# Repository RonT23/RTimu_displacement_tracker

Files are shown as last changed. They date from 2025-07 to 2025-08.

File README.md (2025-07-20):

# Real-Time Displacement Tracker

## Overview 

This project involves the design of a device used to track the displacement of a  moving building under seismic activity. It was developed as part of the final project for the Multivariable Control Systems course in the MSc program in Control Systems and Robotics. The primary goal of the device is to monitor and provide real-time state feedback for controllers applied to seismically controlled buildings.

## The Idea

Consider a building equipped with static control mechanisms, such as elastic dampers installed at its base. These dampers mitigate high-frequency vibrations caused by seismic activity and help protect the building. However, not all seismic waves are fully absorbed—residual vibrations can still propagate and cause structural damage.

The concept proposed in the paper *Robust control of base-isolated structures: Theory and experiments* (-*Kelly, Leitmann and Soldatos*), suggests that that a robust controller applied at the base of an elastomeric-isolated structure can effectively suppress superstructure motion. Their analysis provides critical design constraints for the sensor unit, including the need for high-fidelity base displacement and velocity measurements, low latency, and sufficient dynamic range to capture large isolator displacements and velocities. This project focuses on designing the sensing component that would support such a control system by providing accurate, real-time motion data.

## Hardware

* MPU6050 IMU – Inertial Measurement Unit for retrieving acceleration and gyroscope data.
* FireBeetle ESP32-C6 Mini – Microcontroller used for data acquisition, processing, and communication.
* 3D-Printed Casing – Protective enclosure for the sensor and electronic components.
* USB Cable – Used for both power supply and serial communication with a host computer.

The MPU6050 IMU communicates with the ESP32-C6 Mini microcontroller via the I2C protocol. Use the following wiring configuration to connect the sensor to the microcontroller.

<div align="center">

<table>
  <thead>
    <tr>
      <th><strong>MPU6050 Pin</strong></th>
      <th><strong>ESP32-C6 Mini Pin</strong></th>
    </tr>
  </thead>
  <tbody>
    <tr>
      <td align="center">SCL</td>
      <td align="center">IO19</td>
    </tr>
    <tr>
      <td align="center">SDA</td>
      <td align="center">IO20</td>
    </tr>
    <tr>
      <td align="center">VCC</td>
      <td align="center">3V3</td>
    </tr>
    <tr>
      <td align="center">GND</td>
      <td align="center">GND</td>
    </tr>
  </tbody>
</table>

</div>

The ESP32-C6 Mini connects to a host computer over USB for data transfer and power. To secure the electronic components, use the provided 3D model casing (`case.stl`). **Caution**: Ensure that the sensor is oriented correctly within the case—align the axis arrows on the top of the casing with the direction arrows on the sensor's PCB.

## Software 

- ESP-IDF – Software development and hardware configuration framework for ESP32-based SoC's.
- Embedded source code – Firmware for data acquisition and processing as provided in this repository.
- Python scripts – For data visualization and post-processing.

To install the ESP-IDF software please follow the guide provided by the official [webpage](https://docs.espressif.com/projects/esp-idf/en/stable/esp32/get-started/index.html). Once the ESP-IDF tools are installed successfully, make a new project by adding this repository.  

## Programming the Device 

To program the ESP32-C6 device with the provided source code, use the ESP-IDF tools:

```shell
cp -r RTimu_displacement_tracker/esp32_rtdt_app ~/esp
cd ~/esp
. ./esp-idf/export.sh
idf.py set-target esp32c6
idf.py build
idf.py -p /dev/ttyACM0 flash
```

## Build the UI

To build the executable application from the provided Python script, run the following commands on a Linux terminal:

```shell
cd disp_monitor_ui
chmod +x build.sh
./build.sh
```

For windows users use the `build.bat` script simillarly.

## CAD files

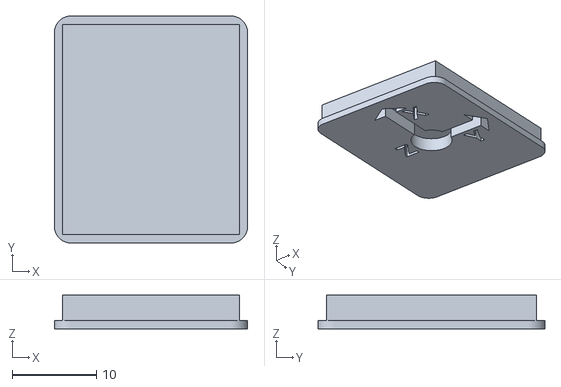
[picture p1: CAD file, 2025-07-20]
stl/top-v2.stl
23.0 x 27.0 x 4.00

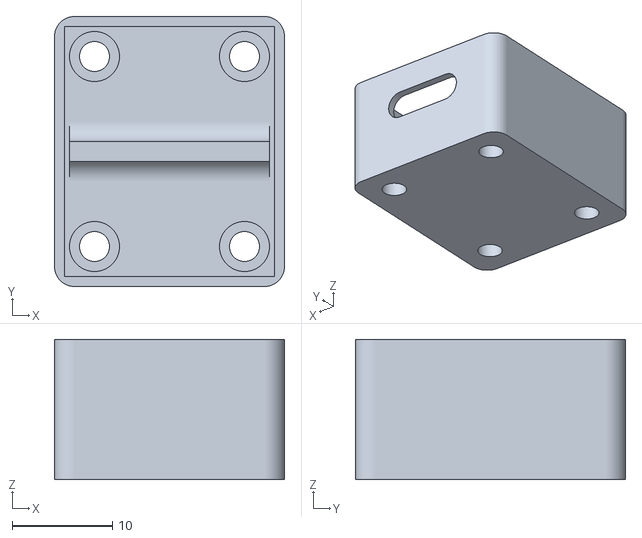
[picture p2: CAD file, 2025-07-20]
stl/base-v2.stl
23.0 x 27.0 x 14.0

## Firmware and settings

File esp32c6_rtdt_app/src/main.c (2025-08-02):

/*
 * Project: Real-Time Displacement Monitoring Unit
 * File: main.c
 * Author: Ronaldo Tsela
 * Date: July 2025
 * 
 * This is the main application entry point for the real-time displacement monitoring unit.
 * It was developed as part of the final project in the "Multivariable Control Systems" course,
 * within the MSc in Control Systems and Robotics program at the National Technical University of Athens (NTUA).
 * 
 * - This application is designed to run on the ESP32 C6.
 * - Developed using the ESP-IDF v5.4.2 framework.
 * - Uses FreeRTOS for application life cycle and execution management.
 * - Requires the MPU6050 IMU. 
 * - It includes initialization routines, data acquisition logic,
 *   and real-time processing for displacement retrival.
 * - The output is printed in CSV format through the main USB to Serial interface
 * - Read the provided documentation for more details.
 */

#include <stdio.h>
#include "freertos/FreeRTOS.h"
#include "freertos/task.h"
#include "esp_log.h"
#include "app_tasks.h"
#include "mpu6050.h"

static task_config_t task_cfg;

void app_main(void)
{
    esp_err_t res;

    // start with default values
    task_cfg.start = false; // keep it idle
    task_cfg.update_rate_ms    = 50;
    task_cfg.accel_noise_floor = 0.5;
    task_cfg.cfg = (mpu6050_config_t){
        .accel_range = 0,      // +-2g
        .gyro_range  = 0,      // +-250 deg/sec
        .dlpf_cfg    = 3,      // DLPF bandwidth: ~44Hz accel / ~42Hz gyro
        .smplrt_div  = 0       // Sample rate = 1kHz / (1 + 0) = 1kHz
    };
    
    // initialize the I2C interface
    res = i2c_master_init(); 
    if (res != ESP_OK) {
        ESP_LOGE("System", "I2C Initialization failed: %s", esp_err_to_name(res));
        vTaskSuspend(NULL);
    }

    // initialize the MPU6050 device
    res = mpu6050_init(I2C_NUM_0);
    if (res != ESP_OK) {
        ESP_LOGE("System", "MPU6050 Initialization failed: %s", esp_err_to_name(res));
        vTaskSuspend(NULL);
    }

    // configure MPU6050 device
    res = mpu6050_config(I2C_NUM_0, &task_cfg.cfg);
    if (res != ESP_OK) {
        ESP_LOGI("System", "MPU6050 Configuration failed: %s", esp_err_to_name(res));
        vTaskSuspend(NULL);
    }

    ESP_LOGI("System", "Initialized");

    // start the system monitor task
    xTaskCreate(
        system_monitor_task,   
        "system_monitor",       
        2048,                 
        NULL,                  
        5,              
        NULL         
    );                  

    // start the sensor readout tasl
    xTaskCreate(
        accel_readout_task,
        "accel_readout",
        2048,
        &task_cfg,
        2,
        NULL
    );

    xTaskCreate(
        command_listener_task,
        "command_listener",
        4096,
        &task_cfg,
        4,
        NULL
    );
}

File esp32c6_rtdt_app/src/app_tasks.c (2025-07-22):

#include "app_tasks.h"

esp_err_t i2c_master_init(void) {
    // Configure the I2C interface
    i2c_config_t conf = {
        .mode               = I2C_MODE_MASTER,
        .sda_io_num         = I2C_MASTER_SDA_IO,
        .scl_io_num         = I2C_MASTER_SCL_IO,
        .sda_pullup_en      = GPIO_PULLUP_ENABLE,
        .scl_pullup_en      = GPIO_PULLUP_ENABLE,
        .master.clk_speed   = 400000,
        .clk_flags          = 0,
    };

    // Apply the configurations
    esp_err_t res = i2c_param_config(I2C_NUM_0, &conf);
    if (res != ESP_OK) { return res; } 

    // Install the driver.
    // This function allocates internal data structures and hooks up the driver, 
    // so we can use 
    // i2c_master_write_to_device(...);
    // i2c_master_read_from_device(...);
    return i2c_driver_install(I2C_NUM_0, conf.mode, 0, 0, 0);
}

void accel_readout_task(void *pvParameters) {
    task_config_t *config = (task_config_t *)pvParameters;

    esp_err_t res;

    mpu6050_data_t accel_data;
    mpu6050_cal_data_t accel_bias_data;
    motion_state_t state; 
 
    // calibrate the accelerometer readings first
    res = mpu6050_calibrate_accel(I2C_NUM_0, &accel_bias_data);
    if ( res == ESP_OK) {
        ESP_LOGI("Calibration", "%.2f, %.2f, %.2f", accel_bias_data.ax_bias, accel_bias_data.ay_bias, accel_bias_data.az_bias);
    } else {
        ESP_LOGE("Calibration", "Failed: %s", esp_err_to_name(res));
        vTaskSuspend(NULL);
    }

    int64_t last_time = esp_timer_get_time();

    while (1) {
        if (config->start) {

            // Read acceleration
            res = mpu6050_read_accel(I2C_NUM_0, &accel_data);

            // measure integration time difference
            int64_t now = esp_timer_get_time(); // in microseconds
            float dt = (now - last_time) / 1e6f;
            last_time = now;

            process_accel_data(accel_data, accel_bias_data, config->accel_noise_floor, dt, &state);

            if (res == ESP_OK) {
                ESP_LOGI("Acceleration", "%.2f,%.2f,%.2f", state.ax, state.ay, state.az);
                ESP_LOGI("Velocity", "%.2f,%.2f,%.2f", state.vx, state.vy, state.vz);
                ESP_LOGI("Displacement", "%.2f,%.2f,%.2f", state.dx, state.dy, state.dz);
            } else {
                ESP_LOGW("ReadOut", "Failed: %s", esp_err_to_name(res));
            }

        } 
        vTaskDelay(pdMS_TO_TICKS(config->update_rate_ms)); // update rate
    }
}

void process_accel_data(mpu6050_data_t data, mpu6050_cal_data_t bias, float noise_threshold, float dt, motion_state_t *state) {
    // Bias Compensation
    float ax = data.ax - bias.ax_bias;
    float ay = data.ay - bias.ay_bias;
    float az = data.az - bias.az_bias;

    // Noise Filtering
    if (fabs(ax) < noise_threshold) ax = 0;
    if (fabs(ay) < noise_threshold) ay = 0;
    if (fabs(az) < noise_threshold) az = 0;

    // Stillness Detection with Hold Time 
    float stationary_threshold = 0.05;
    int hold_cycles = 10;  // Number of consecutive samples to confirm stillness

    // Persistent counters for each axis
    static int ax_still_count = 0;
    static int ay_still_count = 0;
    static int az_still_count = 0;

    // X-axis
    if (fabs(ax) < stationary_threshold) {
        ax_still_count++;
        if (ax_still_count >= hold_cycles) {
            state->vx = 0;
        }
    } else {
        ax_still_count = 0;
        state->vx += ax * dt;
        state->dx += state->vx * dt;
    }

    // Y-axis
    if (fabs(ay) < stationary_threshold) {
        ay_still_count++;
        if (ay_still_count >= hold_cycles) {
            state->vy = 0;
        }
    } else {
        ay_still_count = 0;
        state->vy += ay * dt;
        state->dy += state->vy * dt;
    }

    // Z-axis
    if (fabs(az) < stationary_threshold) {
        az_still_count++;
        if (az_still_count >= hold_cycles) {
            state->vz = 0;
        }
    } else {
        az_still_count = 0;
        state->vz += az * dt;
        state->dz += state->vz * dt;
    }

    // Store acceleration in state
    state->ax = ax;
    state->ay = ay;
    state->az = az;
}

void system_monitor_task(void *pvParameters) {
    uint8_t reg;
    uint8_t who_am_i = 0;
    esp_err_t res;

    uint32_t start_time_sec = esp_timer_get_time() / 1000000;

    while (1) {
        uint32_t now_sec = esp_timer_get_time() / 1000000;
        uint32_t uptime = now_sec - start_time_sec;


        ESP_LOGI("SystemMonitor", "Uptime=%lu s", uptime);

        // MPU6050 WHO_AM_I check via I2C
        reg = MPU6050_WHO_AM_I;
        res = i2c_master_write_read_device(I2C_NUM_0, MPU6050_ADDR, &reg, 1, &who_am_i, 1, pdMS_TO_TICKS(1000));
        if (res == ESP_OK && who_am_i == MPU6050_DEVICE_ID) {
            ESP_LOGI("SystemMonitor", "MPU6050 OK");
        } else {
            ESP_LOGE("SystemMonitor", "MPU6050 not responding (%s)", esp_err_to_name(res));
        }

        // Heap Status
        size_t heap_free = heap_caps_get_free_size(MALLOC_CAP_DEFAULT);
        ESP_LOGI("SystemMonitor", "Heap free=%u bytes", heap_free);

        vTaskDelay(pdMS_TO_TICKS(30000)); // repeat every 30 seconds
    }
}
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

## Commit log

2025-07-13 added the esp32 functional codebase for reading and processing accelerometer data from MPU6050
2025-07-20 added the STL files
    [base-v2.stl, top-v2.stl]
2025-08-02 made the configuration structure variable global to avoid stack cleansing after initialization
    [main.c]
